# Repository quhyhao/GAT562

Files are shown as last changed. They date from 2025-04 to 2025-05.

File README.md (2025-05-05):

# GAT562
GAT562 Mesh Trial Tracker

GAT562 Mesh Trial Tracker是基于nRF52840和SX1262设计的通讯定位终端，支持LoRa和蓝牙5.0。集成电源接口(5V USB、2500mA锂电池），内置1.3英寸TFT显示屏和GPS模块，具有强大的远程通信能力、可扩展性和低功耗设计。

GAT562 Mesh Trial Tracker与Meshtastic完全兼容，可以在Meshtastic网络中更新体验最新的功能。Meshtastic是一个社区驱动的开源项目，它允许在没有任何现有或可靠通信基础设施的地区合理的使用LoRa无线电进行远程离网通信。

GAT562 Mesh Trial Tracker与RAK4631模组IO完全兼容，可以烧录RAK4631固件；

优势
去中心化：不依赖中央服务器或基站，每个设备都可作为中继节点转发信息，网络中没有单点故障，即使部分节点出现问题，也不影响整体通信，网络的可靠性和稳定性更高。

长距离通信：利用 LoRa 等无线通信技术，可实现数公里甚至更远距离的通信，在无网络覆盖的偏远地区或广阔的户外空间优势明显。

离线通信：无需依赖互联网或移动网络，在没有手机信号或 Wi-Fi 的地方也能正常通信，满足特殊场景下的通信需求。

低功耗：采用低功耗的蓝牙低功耗（BLE）技术等，对硬件设备的电池消耗较小，可长时间使用，适合携带式设备，减少了充电的频率和难度。

开源可定制：软件开源，开发者能根据自身需求自由修改和扩展代码，进行二次开发，添加新功能或优化现有功能，满足不同用户的个性化需求。

跨平台兼容：支持多种硬件设备和操作系统，用户可选择适合自己的设备接入网络，如手机、平板电脑等，方便不同设备的用户之间进行通信。

成本较低：使用的硬件通常是价格较为低廉的开源硬件模块，相比专业的通信设备，成本大幅降低，易于推广和使用。

用户界面友好：设计了直观、简洁的用户界面，即使是非技术人员也能快速上手，方便用户进行设备配置、信息发送、位置共享等操作。

DIY说明

将gerber文件整个上传至嘉立创PCB，选择FR4材质——数量（根据自身需求）——PCB厚度选择1.0mm——其他都按照默认选择下单即可完成PCB下单制作。
根据BOM文件购买对应规格的元器件，GAT562 mehs module需要到淘宝店铺（加特物联）下单购买，其余元器件按照BOM规格在立创商城即可下单购买。
按照GAT562 Mesh Trial Tracker V1.3 Top贴片图进行手工焊接，焊接完成后进行组装测试，恭喜你完成了属于自己的meshtastic设备。

申明
外壳文件为3D打印文件，未经许可禁止商用，如涉及侵权自行承担后果，我方概不负责。

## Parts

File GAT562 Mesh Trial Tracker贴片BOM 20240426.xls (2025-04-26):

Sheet: 贴片BOM
GAT562 Mesh Trial Tracker贴片BOM
版本：V1.3
序号 | 元件名称 | 规格 | 元件位置 | 数量 | 封装类型 | 备注
1 | PCB | LoRamesh Tracker L2 FR4 68*43mm绿色表面喷锡工艺 |  | 1 | SMD
2 | 贴片IC | 充电管理芯片TP4057 SOT23-6 | U1 | 1 | SMD
3 | 贴片模组 | GAT562 Mesh module | U2 | 1 | SMD
4 | 贴片模组 | GPS模组移远L76K | U3 | 1 | SMD
5 | 贴片IC | 降压芯片ME6211C33M5G SOT-23-5 | U4 | 1 | SMD
6 | 贴片陶瓷电容 | CAP MLCC 100pFF X5R ±10% 16V 0402 | C14 | 1 | SMD
7 | 贴片陶瓷电容 | CAP MLCC 0.1uF X5R ±10% 16V 0402 | C1, C4，C6, C8, C9, C11, C12，C13, C18,C20,C21 | 11 | SMD
8 | 贴片陶瓷电容 | CAP MLCC 2.2uF NPO ±5% 16V 0402 | C2,C10 | 2 | SMD
9 | 贴片陶瓷电容 | CAP MLCC 10uF X5R ±10% 16V 0402 | C3, C5, C7, C17,C19 | 5 | SMD
10 | 贴片电阻 | RES 0Ω ±5% 1/16W SMD 0402 | R12, R17, R18, R20, R21, R26 | 6 | SMD
11 | 贴片电阻 | RES 680Ω ±5% 1/16W SMD 0402 | R2 | 1 | SMD
12 | 贴片电阻 | RES 1KΩ ±5% 1/16W SMD 0402 | R11, R13,R17 | 3 | SMD
13 | 贴片电阻 | RES 4.7KΩ ±5% 1/16W SMD 0402 | R9, R10，R19, R22,R14 | 5 | SMD
14 | 贴片电阻 | RES 5.1KΩ ±5% 1/16W SMD 0402 | R4, R5 | 2 | SMD
15 | 贴片电阻 | RES 10KΩ ±5% 1/16W SMD 0402 | R1, R3,R8,R15, R16,R27, R28 | 7 | SMD
16 | 贴片电阻 | RES 1MΩ ±5% 1/16W SMD 0402 | R6 | 1 | SMD
17 | 贴片电阻 | RES 1.5MΩ ±5% 1/16W SMD 0402 | R7 | 1 | SMD
18 | 贴片LED | 贴片LED 发光二极管 红灯0603 | LED1 | 1 | SMD
 | 贴片LED | 贴片LED 发光二极管 黄绿灯0603 | LED2 | 1 | SMD
19 | 贴片LED | 贴片LED 发光二极管 翠绿灯0603 | LED3 | 1 | SMD
20 | 贴片LED | 贴片LED 发光二极管 蓝灯0603 | LED4 | 1 | SMD
21 | 贴片按键 | 2*4*3.5mm 侧按贴片按键 | RST1 | 1 | SMD
22 | 贴片USB | TYPE C连接器12PIN，MODE:U262-161N-4BVC11/C319148 | CON1 | 1 | SMD
23 | 贴片二极管 | SS24 SOD-123 | D2,D7 | 2 | SMD
24 | 贴片二极管 | LRB521G SOD-723 | D6 | 1 | SMD
 | 贴片二极管 | IRLML5203TR SOT23 | Q3 | 1 | SMD
25 | 贴片三极管 | L8050HQLT1G SOT23 | Q1, Q2,Q4 | 2 | SMD
26 | 电池座子 | 2PIN卧贴 1.25mm 间距 | BAT1 | 1 | SMD
27 | 插件天线 | GPS陶瓷天线18*18*4mm | ANT1 | 1 | DIP
28 | 插件按键 | 三脚插件卧式轻触开关4.5*4.5*3.8 | S1 | 1 | DIP
29 | 插件开关 | 侧脚拨动开关 支架 SK12D07VG3 VG4 4mm柄高 | SW1 | 1 | DIP
30 | 插件OLED | 1.3寸OLED显示屏驱动SSD1306屏 4PIN：VCC GND SCL SDA | OLED | 1 | DIP
31 | 铜柱 | 单通六角铜柱M3*5+3mm |  | 1 | MID
32 | 主板螺丝 | M2*5十字自攻螺丝 |  | 4 | MID
33 | 外壳螺丝 | M3*10十字沉头螺丝 |  | 4 | MID
34 | 显示屏螺丝 | M3*4十字平头螺丝 |  | 2 | MID
35 | 转接线 | ipex转SMA外螺内孔转接线，线长60mm |  | 1 | MID
36 | 天线 | 胶棒天线50mm长，SMA内螺内针 |  | 1 | MID
37 | 导光柱 | LDP2.0-9.0mm透明款平头T型 |  | 1 | MID
38 | 电池 | 锂电池包104050，出线长度60mm |  | 1 | MID
 | 外壳 | 70*48*27mm外壳 3D打印外壳 |  | 1 | MID

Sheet: 变更记录
版本 | 变更内容 | 日期
V1.0 | 新建BOM | 20241219
V1.2 | 新增U4 C21 R8 C9 C10 C19 C20 | 20250216
 | 增加显示屏螺丝 | 20250225
V1.3 | 新增Q3 Q4 R17 | 20250318

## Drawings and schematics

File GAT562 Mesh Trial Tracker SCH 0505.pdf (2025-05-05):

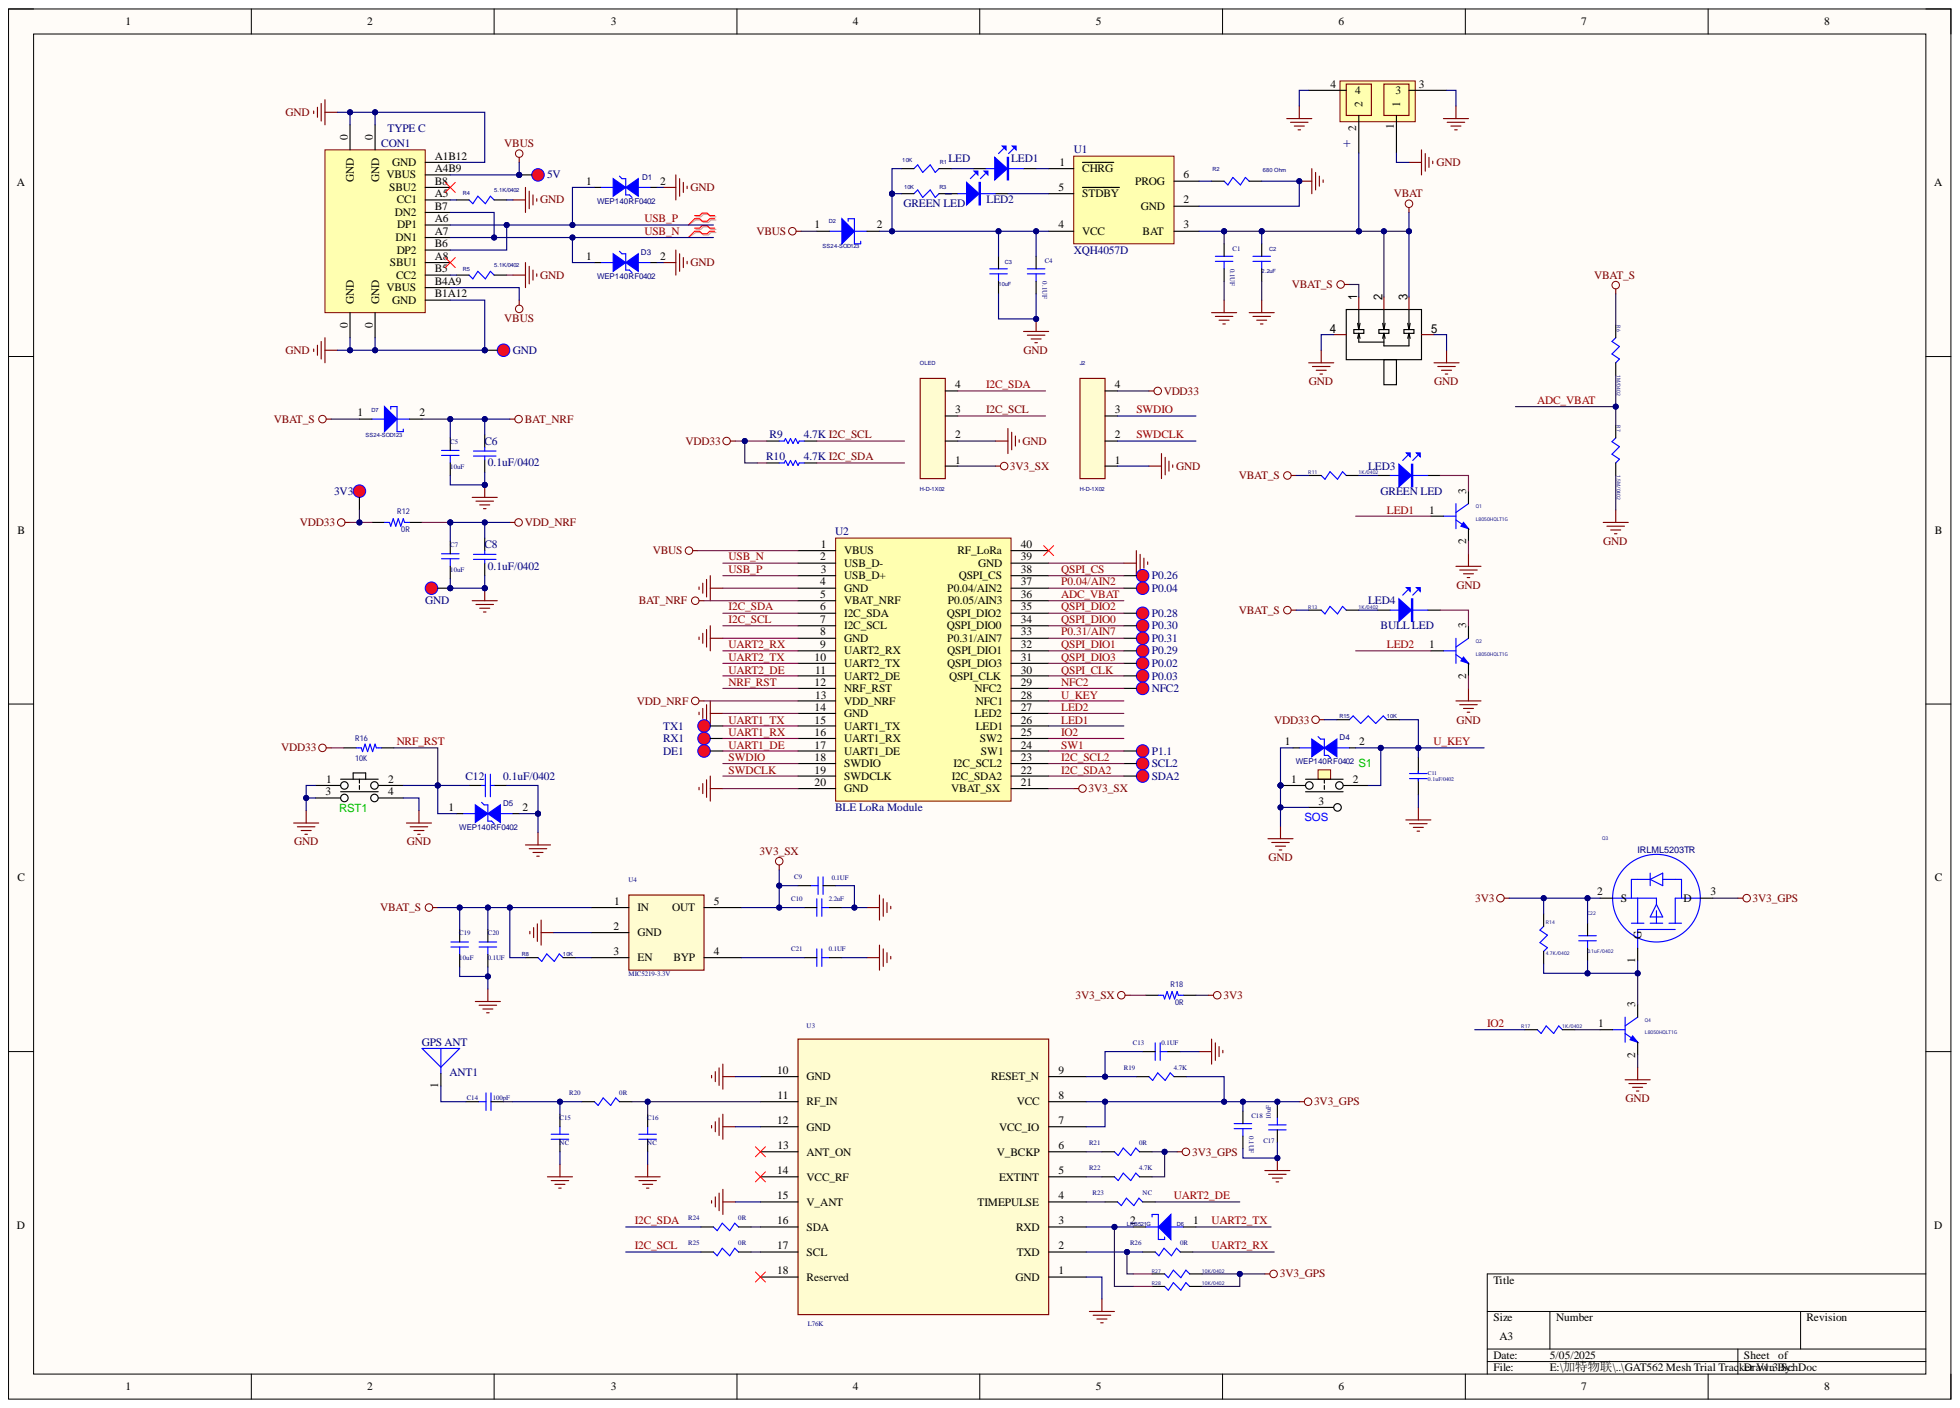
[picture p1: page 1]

TYPE C

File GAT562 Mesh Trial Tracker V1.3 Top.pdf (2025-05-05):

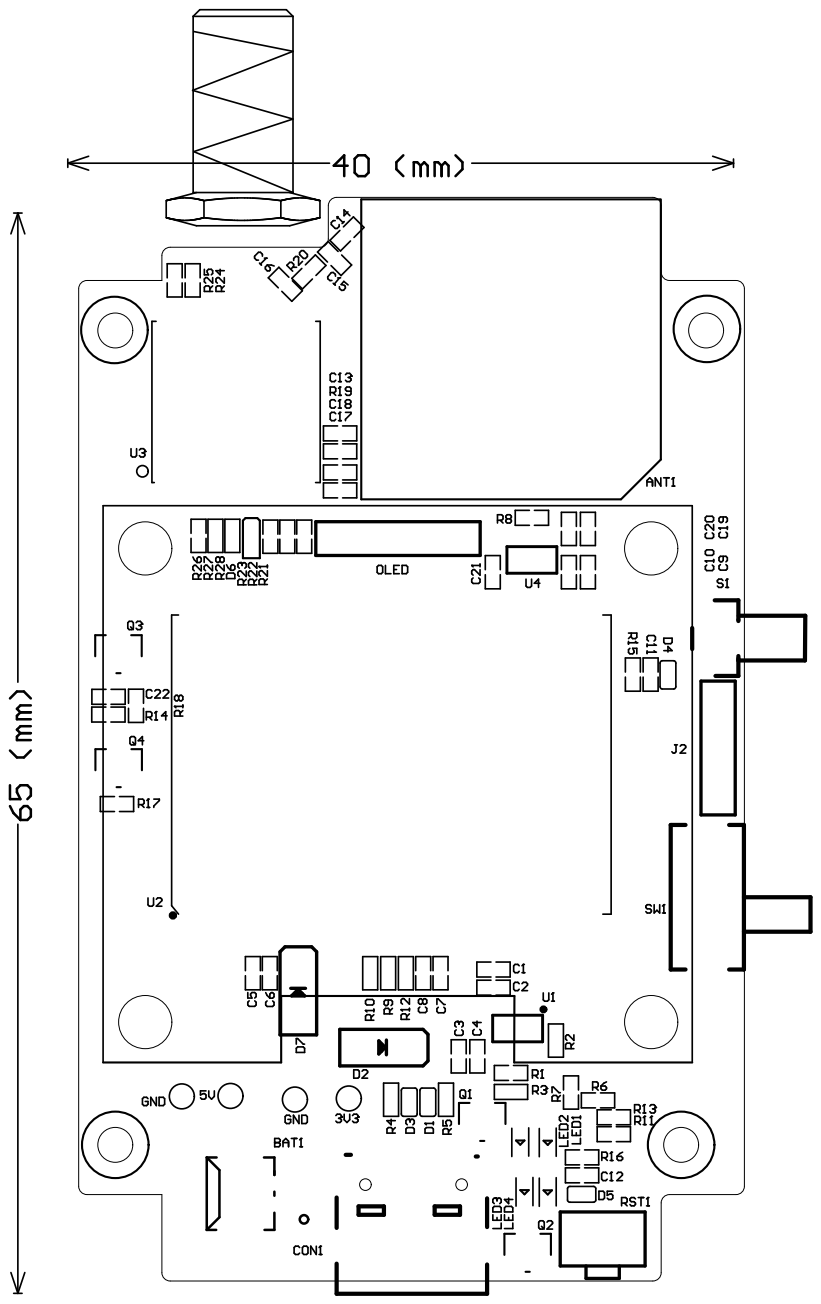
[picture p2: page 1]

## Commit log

2025-04-26 Add manufactur files
    [GAT562 Mesh Trial Tracker贴片BOM 20240426.xls]
2025-05-12 Add files via upload
    GAT562 mesh module 封装
    [gat562 mesh module.PcbLib]
